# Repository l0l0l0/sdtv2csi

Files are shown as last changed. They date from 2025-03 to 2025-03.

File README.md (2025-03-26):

# Fork of https://github.com/rniwase/sdtv2csi
Board for converting SDTV analog video to MIPI CSI-2 using Analog Devices ADV7280A-M.
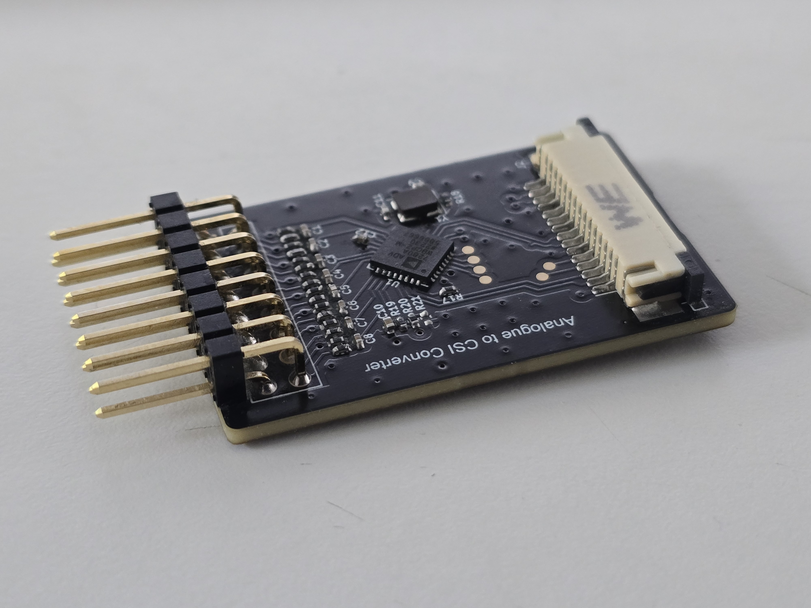
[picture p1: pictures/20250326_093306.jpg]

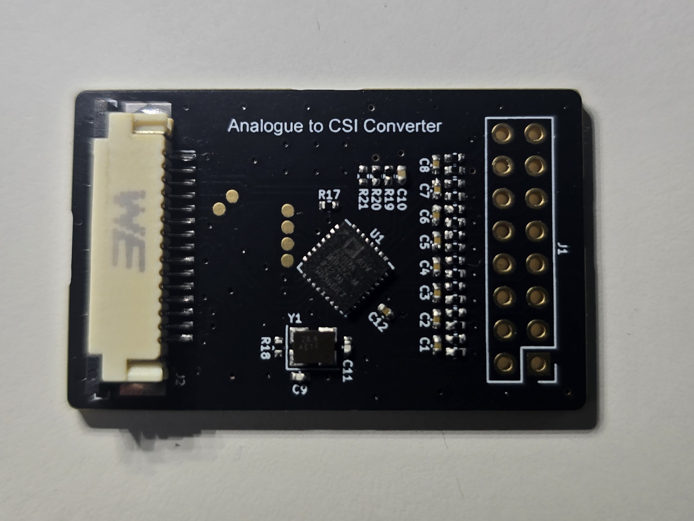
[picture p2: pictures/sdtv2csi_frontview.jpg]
sdtv2csi topview

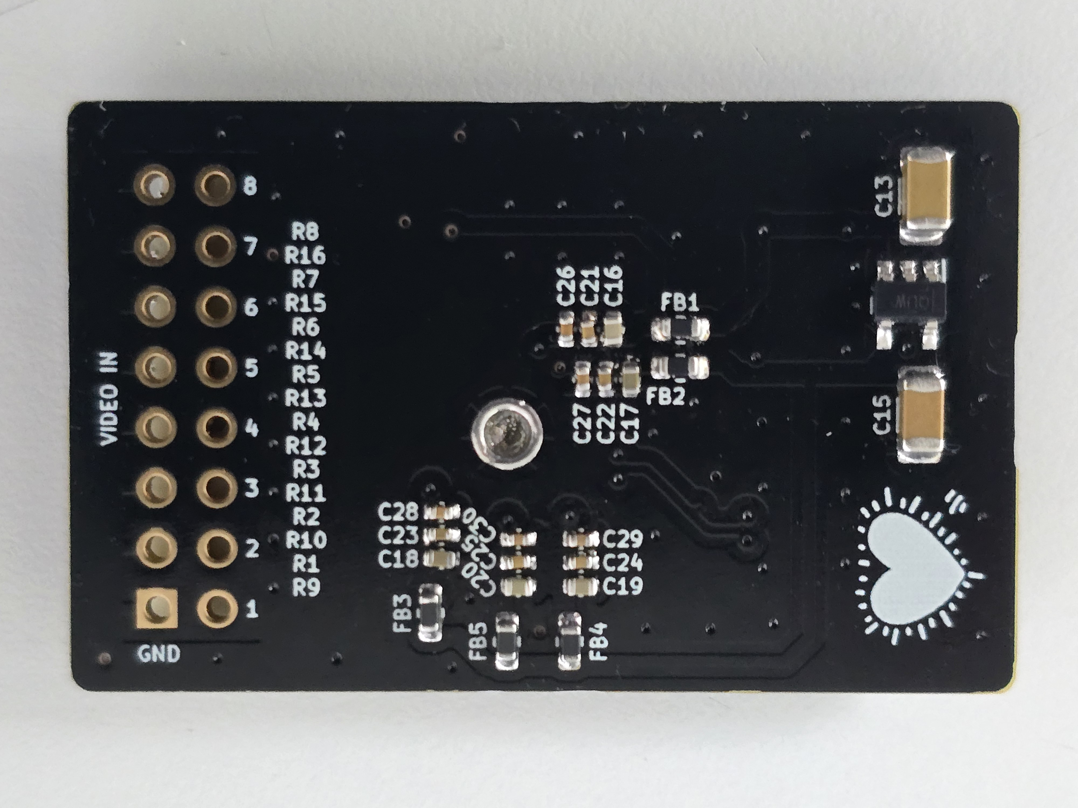
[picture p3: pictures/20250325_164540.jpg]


## In progress ...

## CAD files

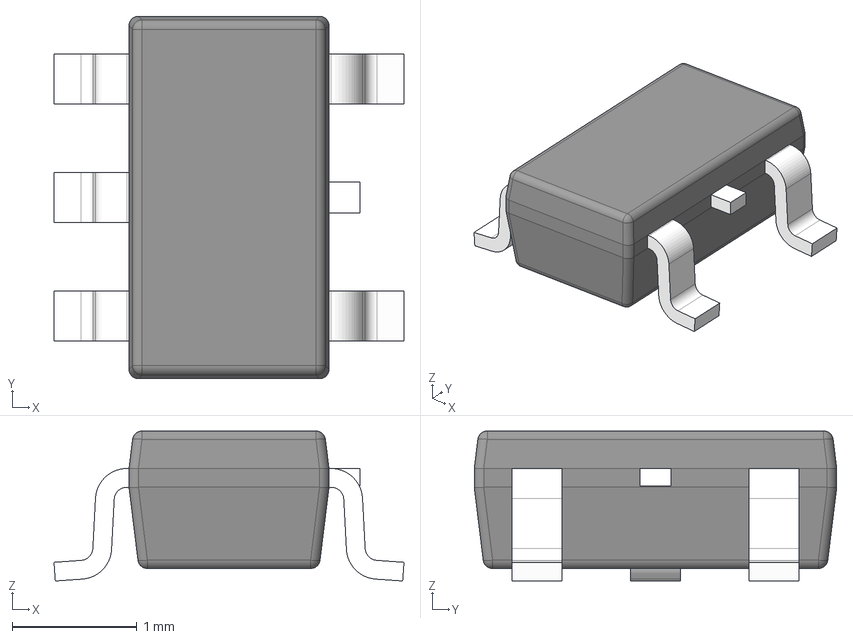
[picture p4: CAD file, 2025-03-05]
pcb/footprint/TLV70218QDBVRQ1.stp
2.80 x 2.90 x 1.20 mm
BODY-SOT
LEAD-SOT x 5
LEAD-DUMMY

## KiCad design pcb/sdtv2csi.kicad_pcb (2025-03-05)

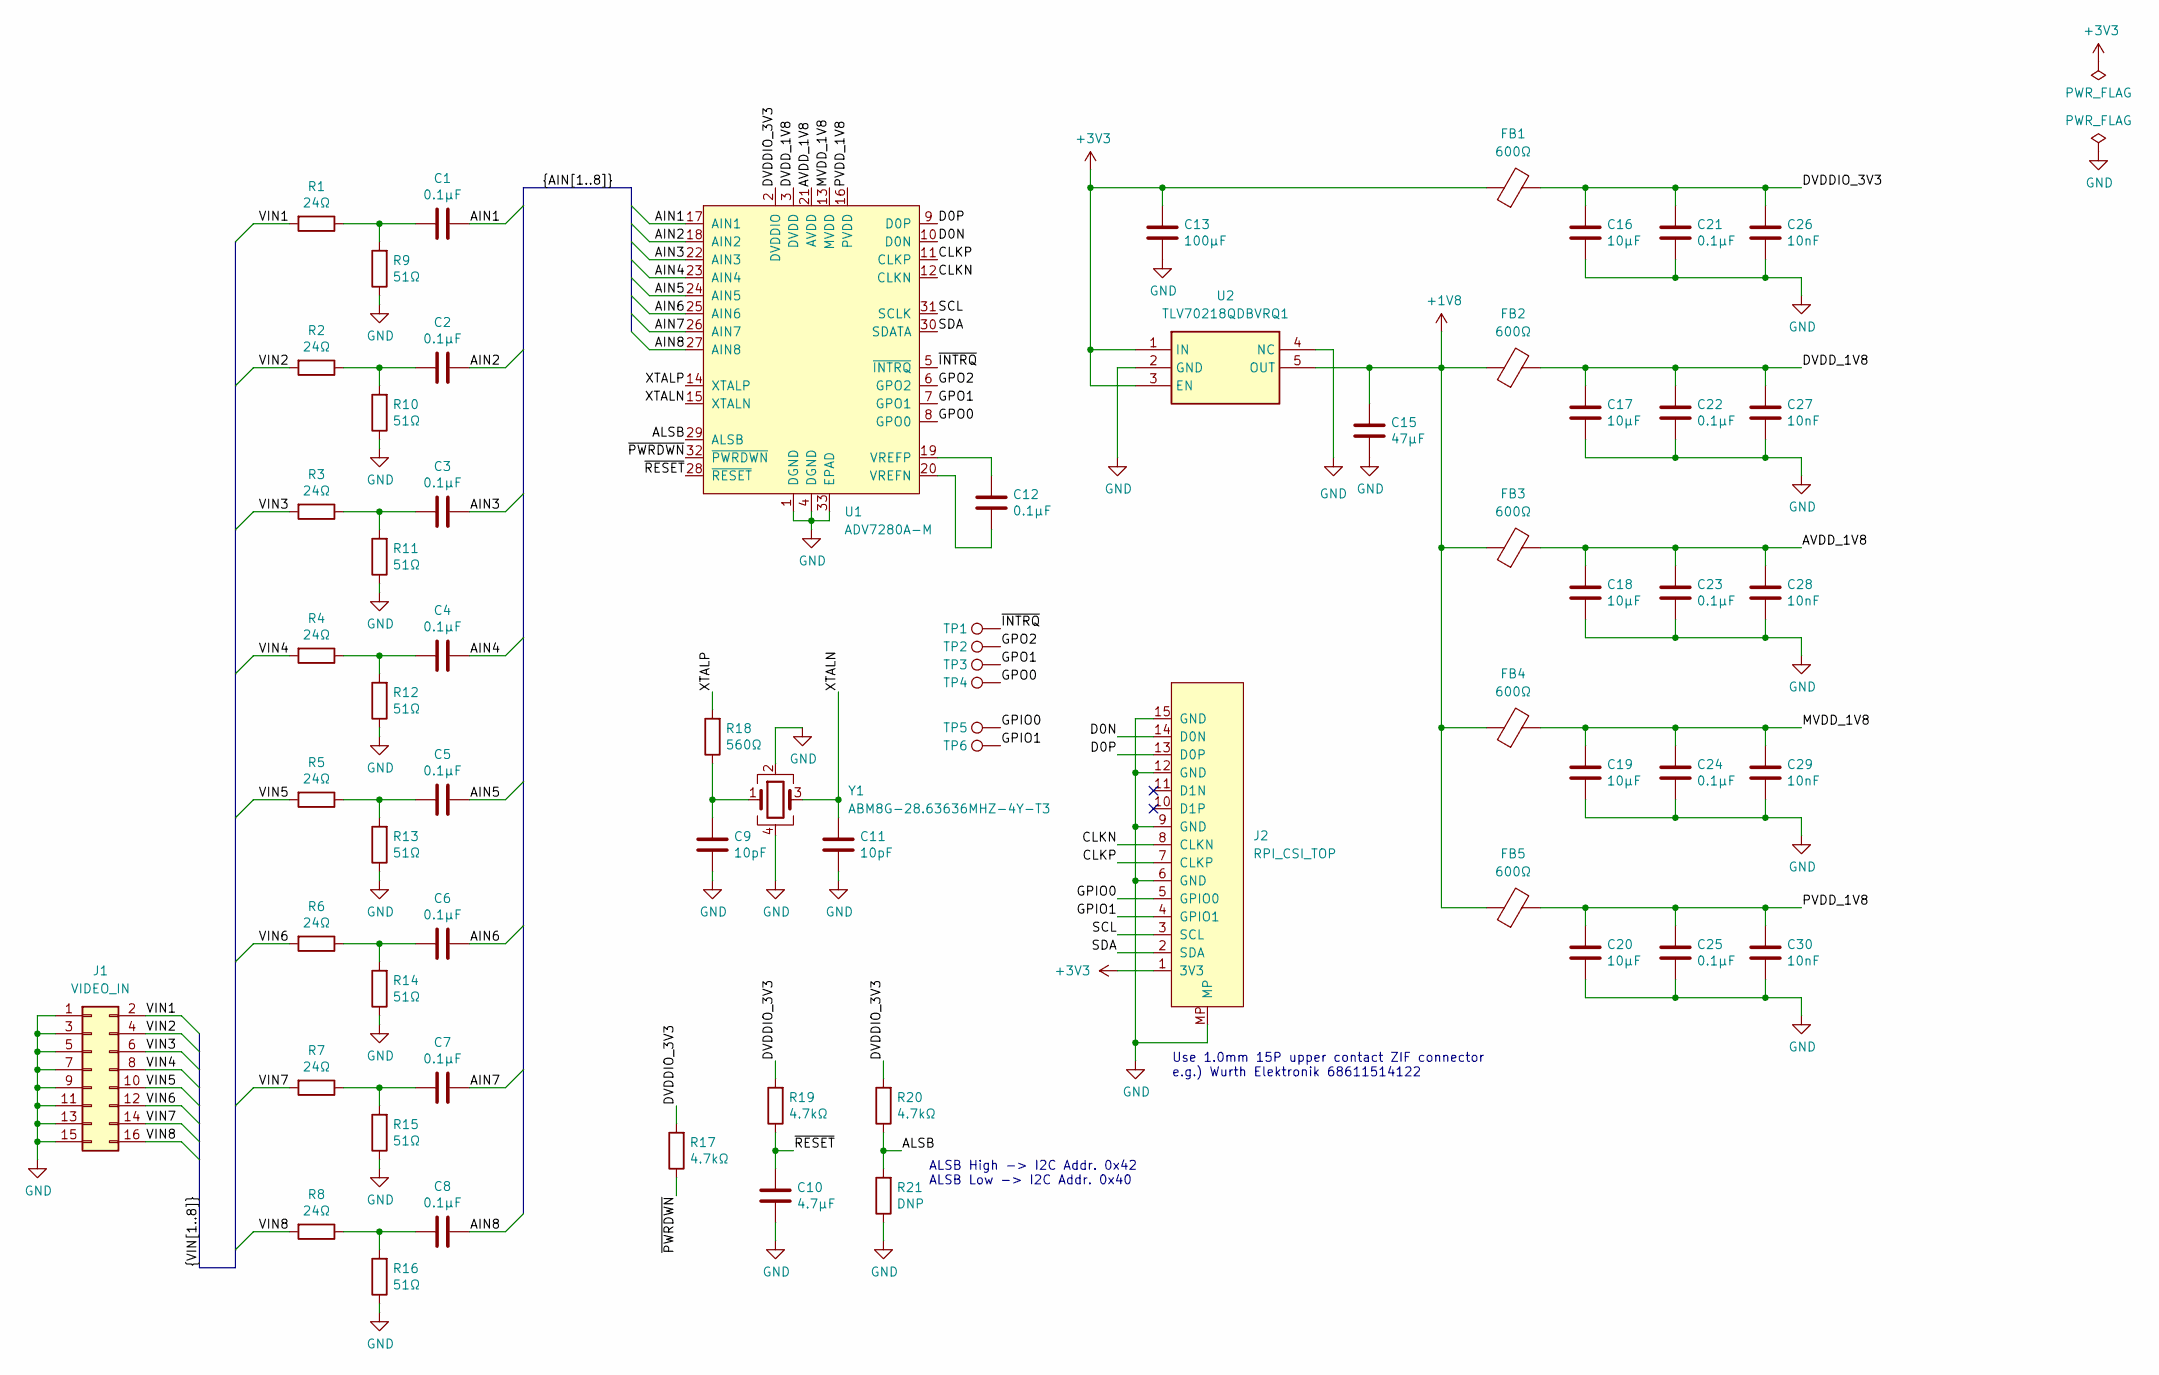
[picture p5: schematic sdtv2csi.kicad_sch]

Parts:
C1, C2, C3, C4, C5, C6, C7, C8, C12, C21, C22, C23, C24, C25: 0.1μF; C_0402_1005Metric
C9, C11: 10pF; C_0402_1005Metric
C10: 4.7μF; C_0402_1005Metric
C13: 100μF; C_1206_3216Metric
C15: 47μF; C_1206_3216Metric
C16, C17, C18, C19, C20: 10μF; C_0402_1005Metric
C26, C27, C28, C29, C30: 10nF; C_0402_1005Metric
FB1, FB2, FB3, FB4, FB5: 600Ω; L_0603_1608Metric
J1: VIDEO_IN; PinHeader_2x08_P2.54mm_Vertical
J2: RPI_CSI_TOP; TE_1-84953-5_1x15-1MP_P1.0mm_Horizontal
R1, R2, R3, R4, R5, R6, R7, R8: 24Ω; R_0402_1005Metric
R9, R10, R11, R12, R13, R14, R15, R16: 51Ω; R_0402_1005Metric
R17, R19, R20: 4.7kΩ; R_0402_1005Metric
R18: 560Ω; R_0402_1005Metric
R21: DNP; R_0402_1005Metric
TP1, TP2, TP3, TP4, TP5, TP6: TestPoint; TestPoint_Pad_D1.0mm
U1: ADV7280A-M; LFCSP-32-1EP_5x5mm_P0.5mm_EP3.25x3.25mm
U2: TLV70218QDBVRQ1; SOT95P280X145-5N; Mouser Part Number 595-TLV70218QDBVRQ1
Y1: ABM8G-28.63636MHZ-4Y-T3; Crystal_SMD_3225-4Pin_3.2x2.5mm

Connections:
+1V8: C15.1, FB2.1, FB3.1, FB4.1, FB5.1, U2.5 (OUT)
+3V3: C13.1, FB1.1, J2.1 (3V3), U2.1 (IN), U2.3 (EN)
/AIN1: C1.1, U1.17 (AIN1)
/AIN2: C2.1, U1.18 (AIN2)
/AIN3: C3.1, U1.22 (AIN3)
/AIN4: C4.1, U1.23 (AIN4)
/AIN5: C5.1, U1.24 (AIN5)
/AIN6: C6.1, U1.25 (AIN6)
/AIN7: C7.1, U1.26 (AIN7)
/AIN8: C8.1, U1.27 (AIN8)
/ALSB: R20.1, R21.2, U1.29 (ALSB)
/AVDD_1V8: C18.1, C23.1, C28.1, FB3.2, U1.21 (AVDD)
/CLKN: J2.8 (CLKN), U1.12 (CLKN)
/CLKP: J2.7 (CLKP), U1.11 (CLKP)
/D0N: J2.14 (D0N), U1.10 (D0N)
/D0P: J2.13 (D0P), U1.9 (D0P)
/DVDDIO_3V3: C16.1, C21.1, C26.1, FB1.2, R17.2, R19.2, R20.2, U1.2 (DVDDIO)
/DVDD_1V8: C17.1, C22.1, C27.1, FB2.2, U1.3 (DVDD)
/GPIO0: J2.5 (GPIO0), TP5.1
/GPIO1: J2.4 (GPIO1), TP6.1
/GPO0: TP4.1, U1.8 (GPO0)
/GPO1: TP3.1, U1.7 (GPO1)
/GPO2: TP2.1, U1.6 (GPO2)
/MVDD_1V8: C19.1, C24.1, C29.1, FB4.2, U1.13 (MVDD)
/PVDD_1V8: C20.1, C25.1, C30.1, FB5.2, U1.16 (PVDD)
/SCL: J2.3 (SCL), U1.31 (SCLK)
/SDA: J2.2 (SDA), U1.30 (SDATA)
/VIN1: J1.2, R1.2
/VIN2: J1.4, R2.2
/VIN3: J1.6, R3.2
/VIN4: J1.8, R4.2
/VIN5: J1.10, R5.2
/VIN6: J1.12, R6.2
/VIN7: J1.14, R7.2
/VIN8: J1.16, R8.2
/XTALN: C11.1, U1.15 (XTALN), Y1.3
/XTALP: R18.2, U1.14 (XTALP)
/~INTRQ: TP1.1, U1.5 (~INTRQ)
/~PWRDWN: R17.1, U1.32 (~PWRDWN)
/~RESET: C10.1, R19.1, U1.28 (~RESET)
GND: C9.2, C10.2, C11.2, C13.2, C15.2, C16.2, C17.2, C18.2, C19.2, C20.2, C21.2, C22.2, C23.2, C24.2, C25.2, C26.2, C27.2, C28.2, C29.2, C30.2, J1.1, J1.3, J1.5, J1.7, J1.9, J1.11, J1.13, J1.15, J2.6 (GND), J2.9 (GND), J2.12 (GND), J2.15 (GND), J2.MP, R9.1, R10.1, R11.1, R12.1, R13.1, R14.1, R15.1, R16.1, R21.1, U1.1 (DGND), U1.4 (DGND), U1.33 (EPAD), U2.2 (GND), U2.4 (NC), Y1.2, Y1.4
unnamed: C1.2, R1.1, R9.2
unnamed: C2.2, R2.1, R10.2
unnamed: C3.2, R3.1, R11.2
unnamed: C4.2, R4.1, R12.2
unnamed: C5.2, R5.1, R13.2
unnamed: C6.2, R6.1, R14.2
unnamed: C7.2, R7.1, R15.2
unnamed: C8.2, R8.1, R16.2
unnamed: C9.1, R18.1, Y1.1
unnamed: C12.2, U1.20 (VREFN)
unnamed: C12.1, U1.19 (VREFP)

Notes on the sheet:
Use 1.0mm 15P upper contact ZIF connector e.g.) Wurth Elektronik 68611514122
ALSB High -> I2C Addr. 0x42 ALSB Low -> I2C Addr. 0x40

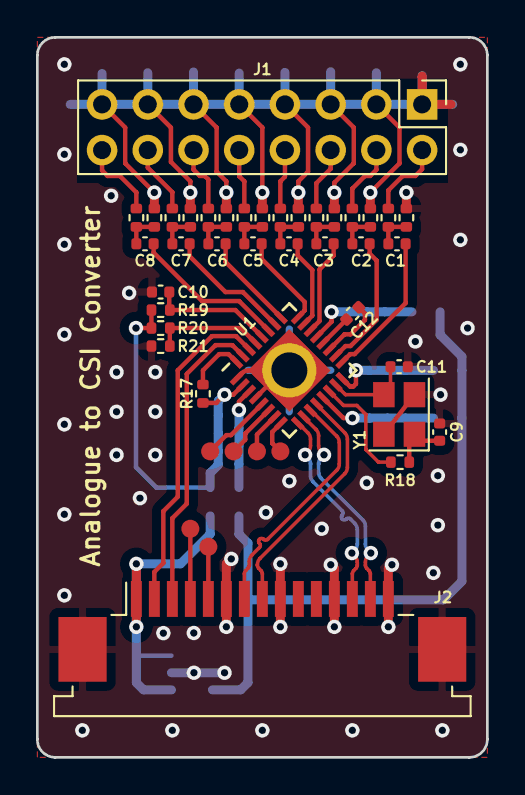
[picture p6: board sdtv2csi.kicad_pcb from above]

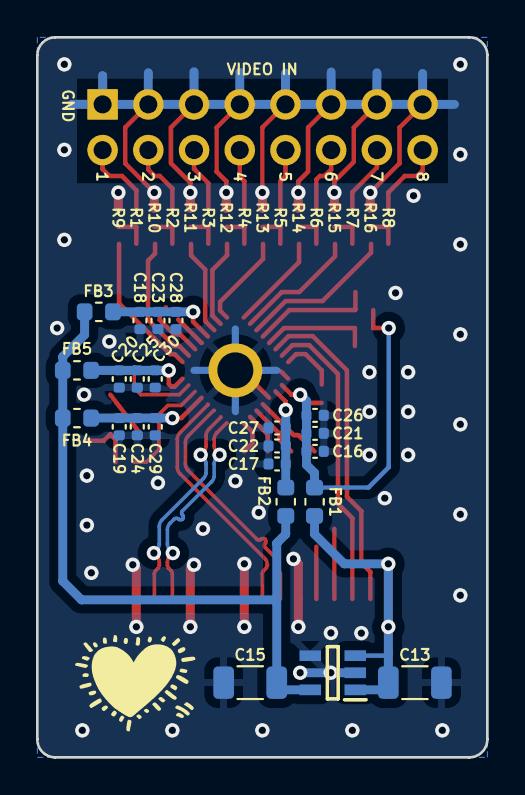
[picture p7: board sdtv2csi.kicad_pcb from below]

Board: 2 copper layers, 25.0 x 40.0 mm, 66 parts (23 on the bottom side), 52 nets.

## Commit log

2025-03-05 Replacement of NJM12888F18 to TLV70218QDBVRQ1
    [TLV70218QDBVRQ1.stp, sdtv2csi.kicad_pcb, sdtv2csi.kicad_sch]
2025-03-05 Update C9 / C10 and change ABM8G
    [sdtv2csi.kicad_pcb, sdtv2csi.kicad_sch]
2025-03-05 Remove via on NC pad
    [sdtv2csi.kicad_pcb]
